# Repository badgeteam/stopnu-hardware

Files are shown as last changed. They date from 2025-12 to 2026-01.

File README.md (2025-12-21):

# STOPNU traffic light controller board

## Introduction

The StopNU board is an interface board design to be used with an Heltec V3 board, with purpose to provide a LoRa synchronized traffic light system.
The board has the ability to process inputs from: an Ambient light sensor, 3 button IO channels, a QWIIC interface.
The board can control LED strips via 5V LED control output lines, and using QWIIC peripherals.
IO is also exposed to the 'Expansion connector', which provides a way to breakout IO to future boards.

## Power

The board will be provided 5V power, stabilized outside of the board.
Because the current consumption is limited to 1A, the board it self cannot provide power to LED's controlled by the board.

Even though 3.3V and 5V pins are provided with the expansion header, the total power of these two power railes combined is limited at 3W.

## Pin-out

### Ambient light sensor

The ambient light sensor this circuit is designed for is the [TEPT4400](https://www.vishay.com/docs/81341/tept4400.pdf), where the sensor is connected between the collector and emitter pin.
The current allowed through the sensor results in a voltage that needs to be decoded by the ESP32 micro controller ADC input pin.

The emitter is is connected to ADC pin GPIO02

### LED control outputs

The LED control output pins are level shifted to 5V TTL, in order to work with the WS2812 addressable LED's or compatible.
The pins are output only as the level shifter only works one way.

| LED output | GPIO |
| --- | --- |
| 1 | GPIO04 |
| 2 | GPIO03 |

### Digital input lines

In order for external input devices to work with the board, 3 input lines have been provided, that are routed through an opto-coupler in order to be more noise resistant.
The IO pins are pulled up to 5V, and need to be pulled down by the input device in order for the board to register an input.

When the pin is pulled down the current through the IO input is 5 mA.

| Button # | GPIO |
| --- | --- |
| 1 | GPIO07 |
| 2 | GPIO06 |
| 3 | GPIO07 |

### QWIIC connector

The QWIIC connector is there to connect external I2C (IIC) sensors and IO modules to the board, providing an extra method of expansion.
The port complies with the pin out and specs as provided by [QWIIC Sparkfun page](https://www.sparkfun.com/qwiic), QWIIC products sold are compatible with this board.

Again for the QWIIC bus 3.3V power supply counts, 3W budget shared with the other peripherals on the board.

| QWIIC pin | GPIO |
| --- | -----  |
| SDA | GPIO34 |
| SCL | GPIO33 |

### Expansion connector

The expansion connector exposes the Heltec V3 pins useable for IO.
The pins that are connected to the buffered outputs on the bottom of the board are also exposed on the header, but without the buffering.

Please be aware that some pins exposed on the header are used by the Heltec V3 internally, and should be used with care.

Here a list of the Heltec V3 board pins and where they connect to on the expansion header.

| pin | GPIO | capable | comments |
| --- | --- | --- | --- |
| 1 | GND | Power | |
| 2 | GND | Power | |
| 3 | GPIO41  | | |
| 4 | GPIO44  | | Heltec V3 UAR_TX |
| 5 | GPIO40  | | Drives Heltec white LED |
| 6 | GPIO43  | | Heltec V3 UART_RX |
| 7 | GPIO39  | | Heltec V3 external power switch |
| 8 | MCU_RST | | Heltec V3 Reset pin |
| 9 | GPIO38  | | Heltec V3 ADC ctrl |
| 10  | GPIO00  | | USER_KEY |
| 11  | GPIO01  | ADC | |
| 12  | GPIO35  | | |
| 13  | GPIO02  | ADC | |
| 14  | GPIO34  | | QWIIC SDA |
| 15  | +3.3V | Power | 3W max (total) |
| 16  | +5V | Power | 3W max (total) |
| 17  | GND | Power | |
| 18  | GND | Power | |
| 19  | GPIO03  | ADC | LED channel 2 |
| 20  | GPIO45  | | |
| 21  | GPIO04  | ADC | LED channel 1 |
| 22  | GPIO33  | | QWIIC SCL |
| 23  | GPIO05  | ADC | Button IN 3 |
| 24  | GPIO46  | | |
| 25  | GPIO06  | ADC/Input only | Button IN 2 |
| 26  | GPIO42  | |
| 27  | GPIO07  | ADC/Input only | Button IN 1 |
| 28  | GPIO26  | | |
| 29  | GND | Power | |
| 30  | GND | Power | |

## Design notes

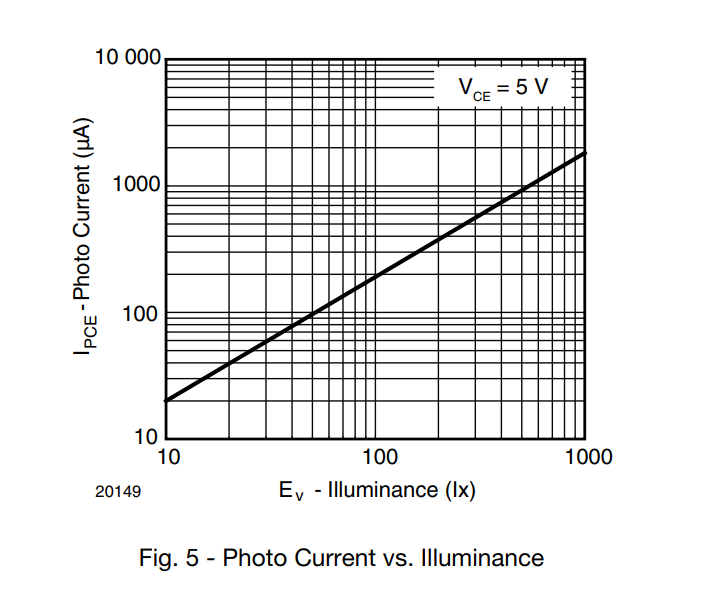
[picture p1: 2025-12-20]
docs/tept4400-i-lum.png

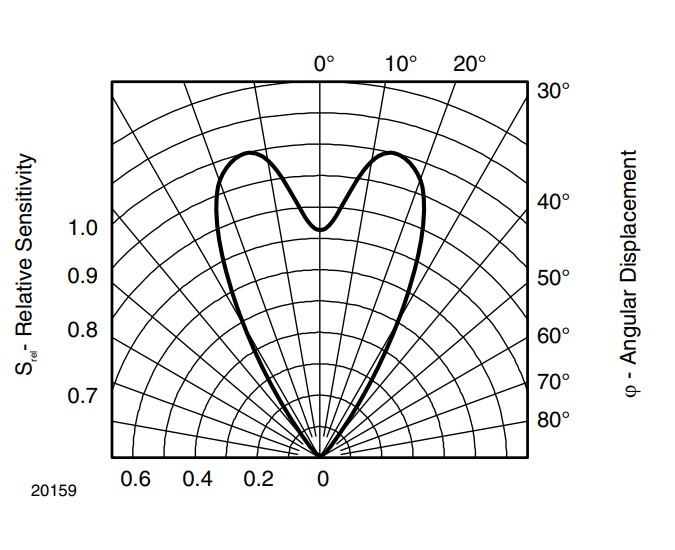
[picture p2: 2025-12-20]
docs/tept4400-directionality.png

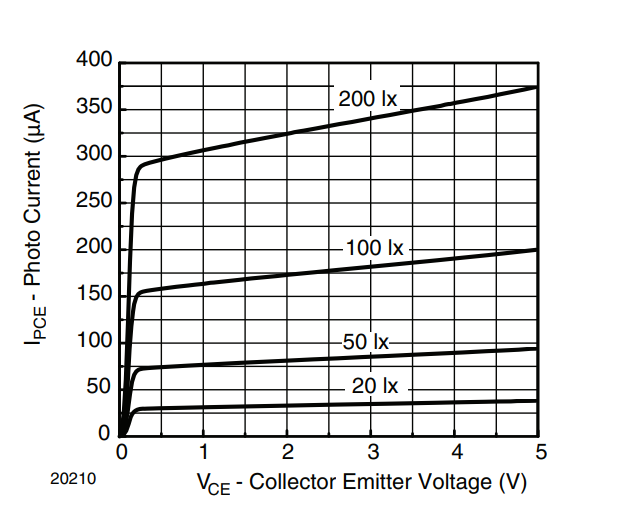
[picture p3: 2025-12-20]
docs/tept4400-i-ce-lux.png

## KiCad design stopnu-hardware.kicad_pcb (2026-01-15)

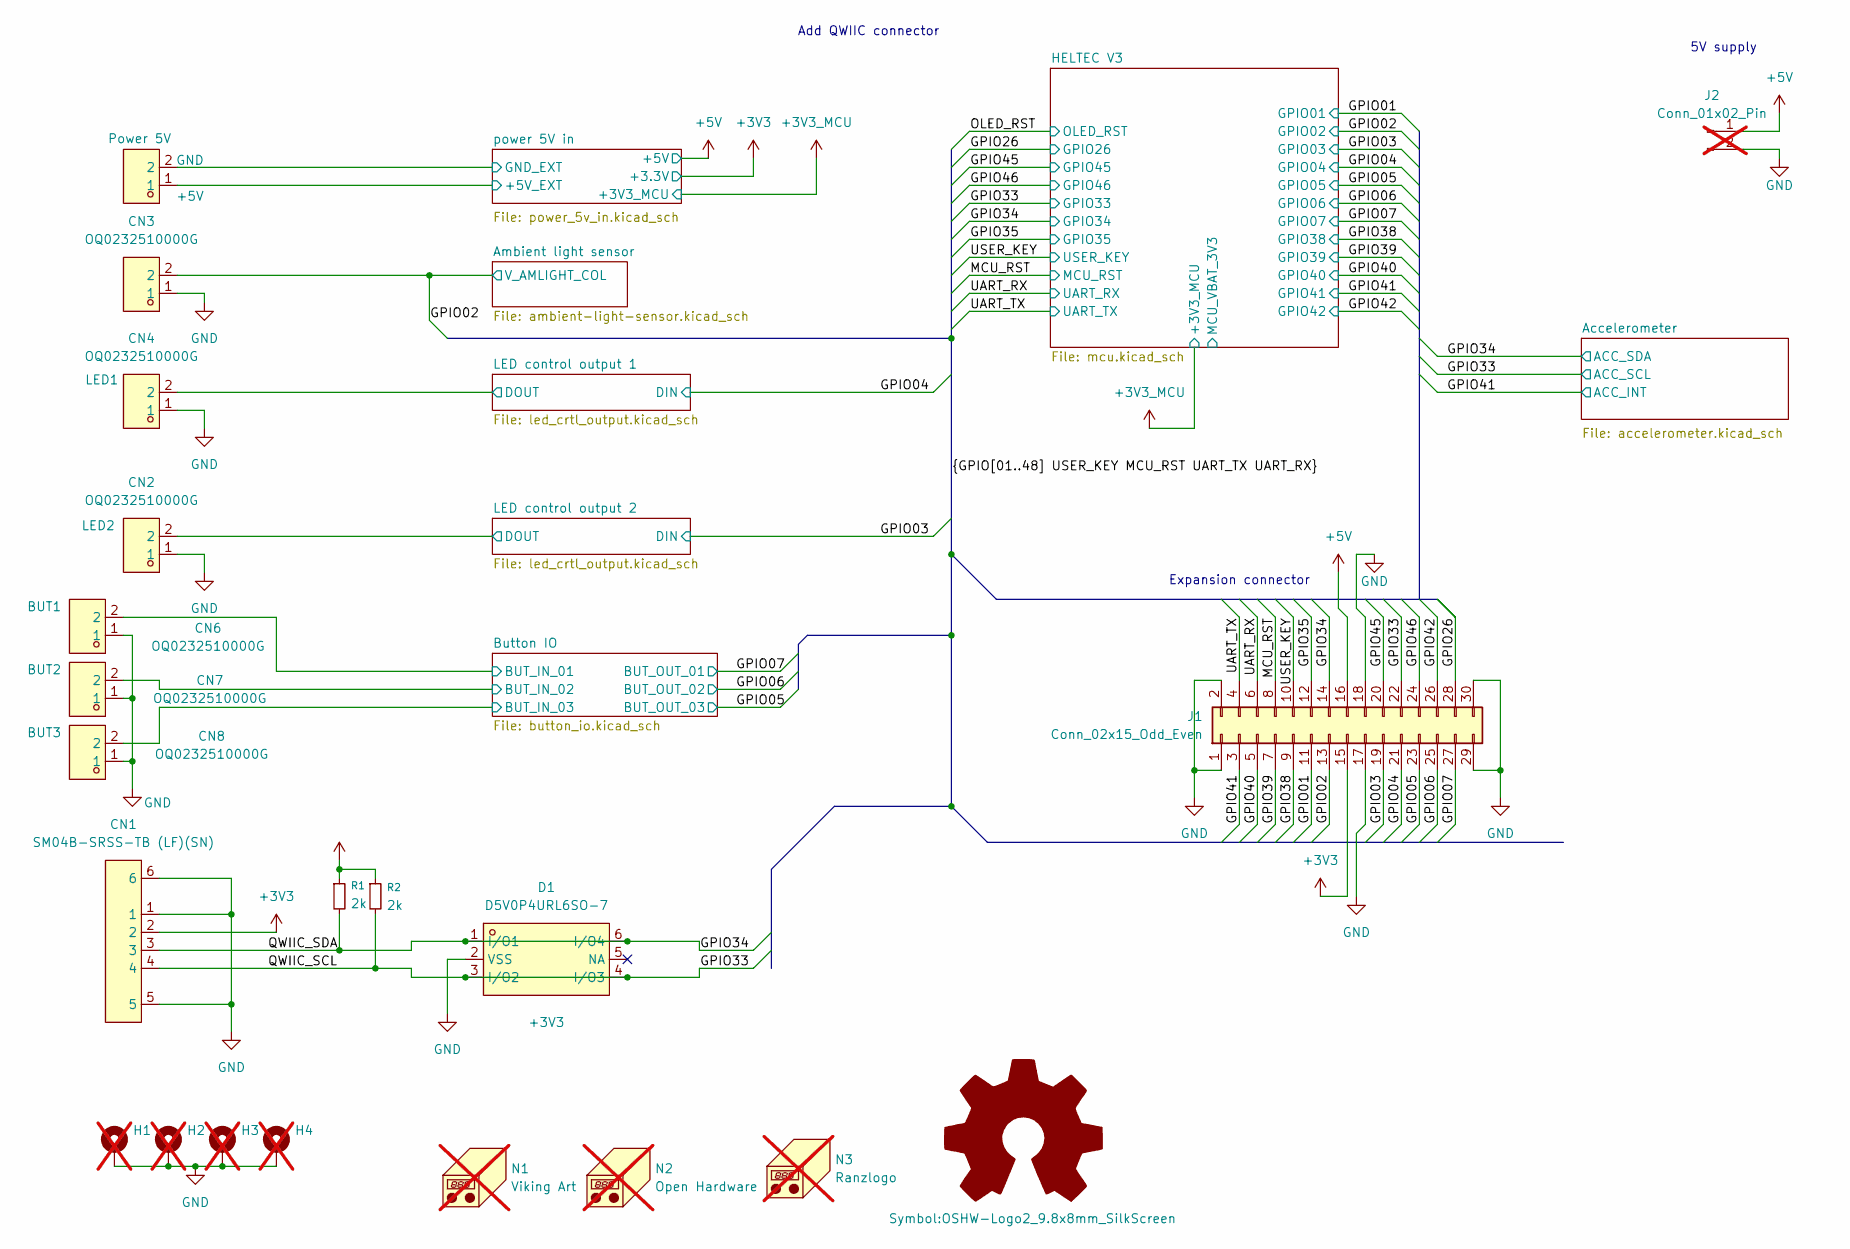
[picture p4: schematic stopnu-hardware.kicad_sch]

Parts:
CN1: SM04B-SRSS-TB (LF)(SN); CONN-SMD_4P-P1.00_SM04B-SRSS-TB-LF-SN; LCSC Part C160404
CN2, CN3, CN4, CN5, CN6, CN7, CN8: OQ0232510000G; CONN-TH_OQ0232510000G; LCSC Part C967073
D1: D5V0P4URL6SO-7; SOT-26_L3.0-W1.6-P0.95-LS2.8-BL; LCSC Part C460591
H1, H2, H3, H4: MountingHole_Pad; MountingHole_4.5mm_Pad_Via; not fitted
J1: Conn_02x15_Odd_Even; PinHeader_2x15_P2.54mm_Horizontal; LCSC C2894995
J2: Conn_01x02_Pin; PinHeader_1x02_P2.54mm_Vertical; LCSC C32713268; not fitted
N1: Viking Art; StopNuVikings; not fitted
N2: Open Hardware; OSHW-Logo2_9.8x8mm_SilkScreen; not fitted
N3: Ranzlogo; goatse_01; not fitted
R1, R2: 2k; R_0603_1608Metric; LCSC C22975

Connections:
+3V3: CN1.2, J1.15, R1.1, R2.1; also elsewhere on the board
+5V: J1.16, J2.1; also elsewhere on the board
/Button IO/BUT_IN_01: CN6.2; also elsewhere on the board
/Button IO/BUT_IN_02: CN7.2; also elsewhere on the board
/Button IO/BUT_IN_03: CN8.2; also elsewhere on the board
/GPIO01: J1.11; also elsewhere on the board
/GPIO02: CN3.2, J1.13; also elsewhere on the board
/GPIO03: J1.19; also elsewhere on the board
/GPIO04: J1.21; also elsewhere on the board
/GPIO05: J1.23; also elsewhere on the board
/GPIO06: J1.25; also elsewhere on the board
/GPIO07: J1.27; also elsewhere on the board
/GPIO26: J1.28; also elsewhere on the board
/GPIO33: CN1.4, D1.3 (I/O2), D1.4 (I/O3), J1.22, R2.2; also elsewhere on the board
/GPIO34: CN1.3, D1.1 (I/O1), D1.6 (I/O4), J1.14, R1.2; also elsewhere on the board
/GPIO35: J1.12; also elsewhere on the board
/GPIO38: J1.9; also elsewhere on the board
/GPIO39: J1.7; also elsewhere on the board
/GPIO40: J1.5; also elsewhere on the board
/GPIO41: J1.3; also elsewhere on the board
/GPIO42: J1.26; also elsewhere on the board
/GPIO45: J1.20; also elsewhere on the board
/GPIO46: J1.24; also elsewhere on the board
/LED control output 1/DOUT: CN4.2; also elsewhere on the board
/LED control output 2/DOUT: CN2.2; also elsewhere on the board
/MCU_RST: J1.8; also elsewhere on the board
/UART_RX: J1.6; also elsewhere on the board
/UART_TX: J1.4; also elsewhere on the board
/USER_KEY: J1.10; also elsewhere on the board
/power 5V in/+5V_EXT: CN5.1; also elsewhere on the board
/power 5V in/GND_EXT: CN5.2; also elsewhere on the board
GND: CN1.1, CN1.5, CN1.6, CN2.1, CN3.1, CN4.1, CN6.1, CN7.1, CN8.1, D1.2 (VSS), H1.1, H2.1, H3.1, H4.1, J1.1, J1.2, J1.17, J1.18, J1.29, J1.30, J2.2; also elsewhere on the board

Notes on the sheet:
5V supply
Add QWIIC connector
Expansion connector

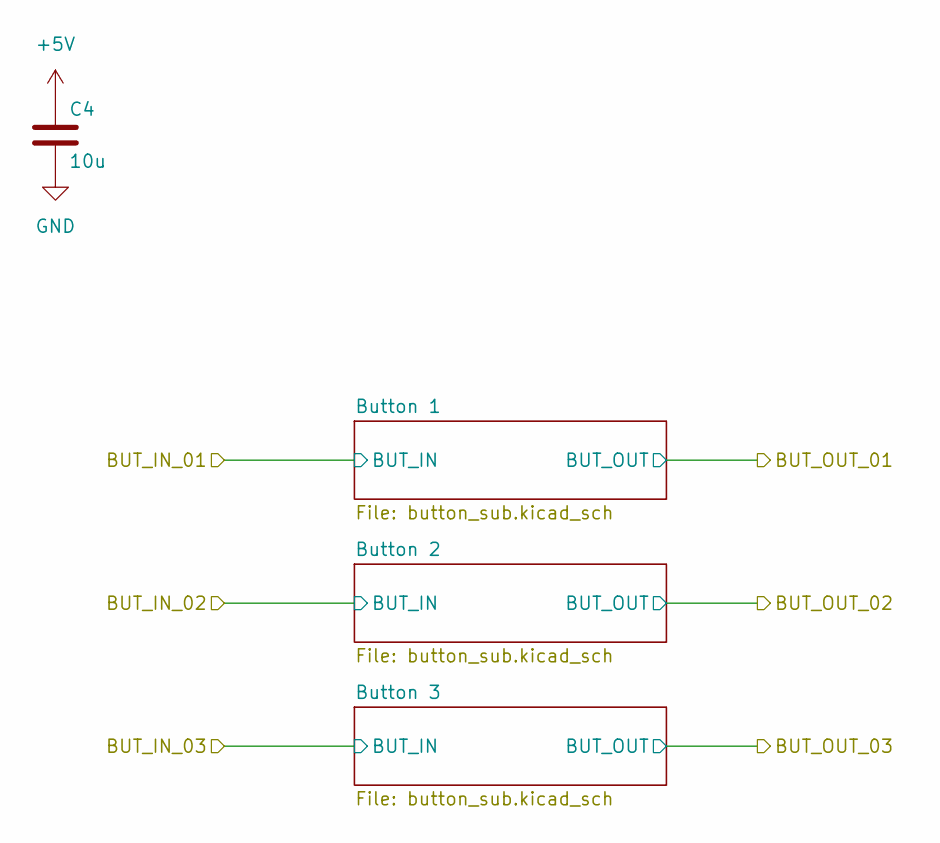
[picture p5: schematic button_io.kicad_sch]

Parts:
C4: 10u; C_0805_2012Metric; LCSC C3039694

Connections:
+5V: C4.1; also elsewhere on the board
GND: C4.2; also elsewhere on the board

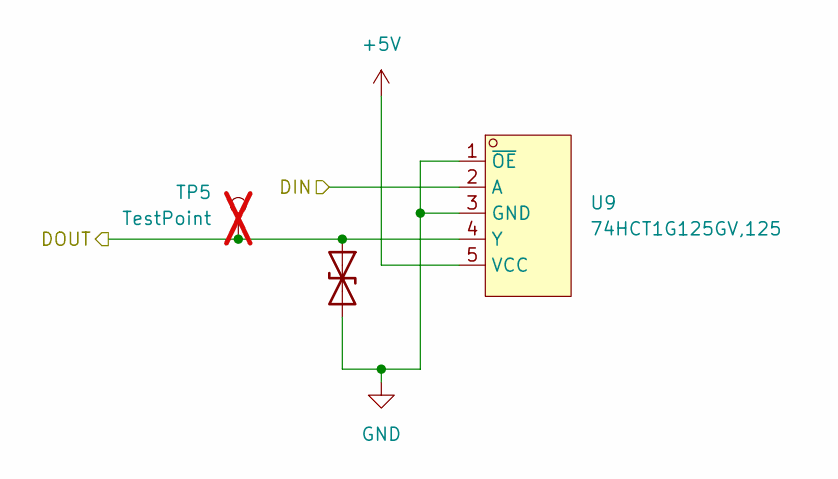
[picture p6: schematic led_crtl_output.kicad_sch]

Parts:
D4: ESD prot.; D_SOD-323; LCSC C22363742
TP5: TestPoint; TestPoint_Pad_D1.0mm; not fitted
U9: 74HCT1G125GV,125; SOT-753_L3.1-W1.7-P0.95-LS3.0-BL; LCSC Part C12502

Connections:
+5V: U9.5 (VCC); also elsewhere on the board
/GPIO04: U9.2 (A); also elsewhere on the board
/LED control output 1/DOUT: D4.1 (A1), TP5.1, U9.4 (Y); also elsewhere on the board
GND: D4.2 (A2), U9.1 (~OE), U9.3 (GND); also elsewhere on the board

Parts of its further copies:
D2: ESD prot.; D_SOD-323; LCSC C22363742
TP3: TestPoint; TestPoint_Pad_D1.0mm; not fitted
U10: 74HCT1G125GV,125; SOT-753_L3.1-W1.7-P0.95-LS3.0-BL; LCSC Part C12502

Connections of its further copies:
+5V: U10.5 (VCC); also elsewhere on the board
/GPIO03: U10.2 (A); also elsewhere on the board
/LED control output 2/DOUT: D2.1 (A1), TP3.1, U10.4 (Y); also elsewhere on the board
GND: D2.2 (A2), U10.1 (~OE), U10.3 (GND); also elsewhere on the board

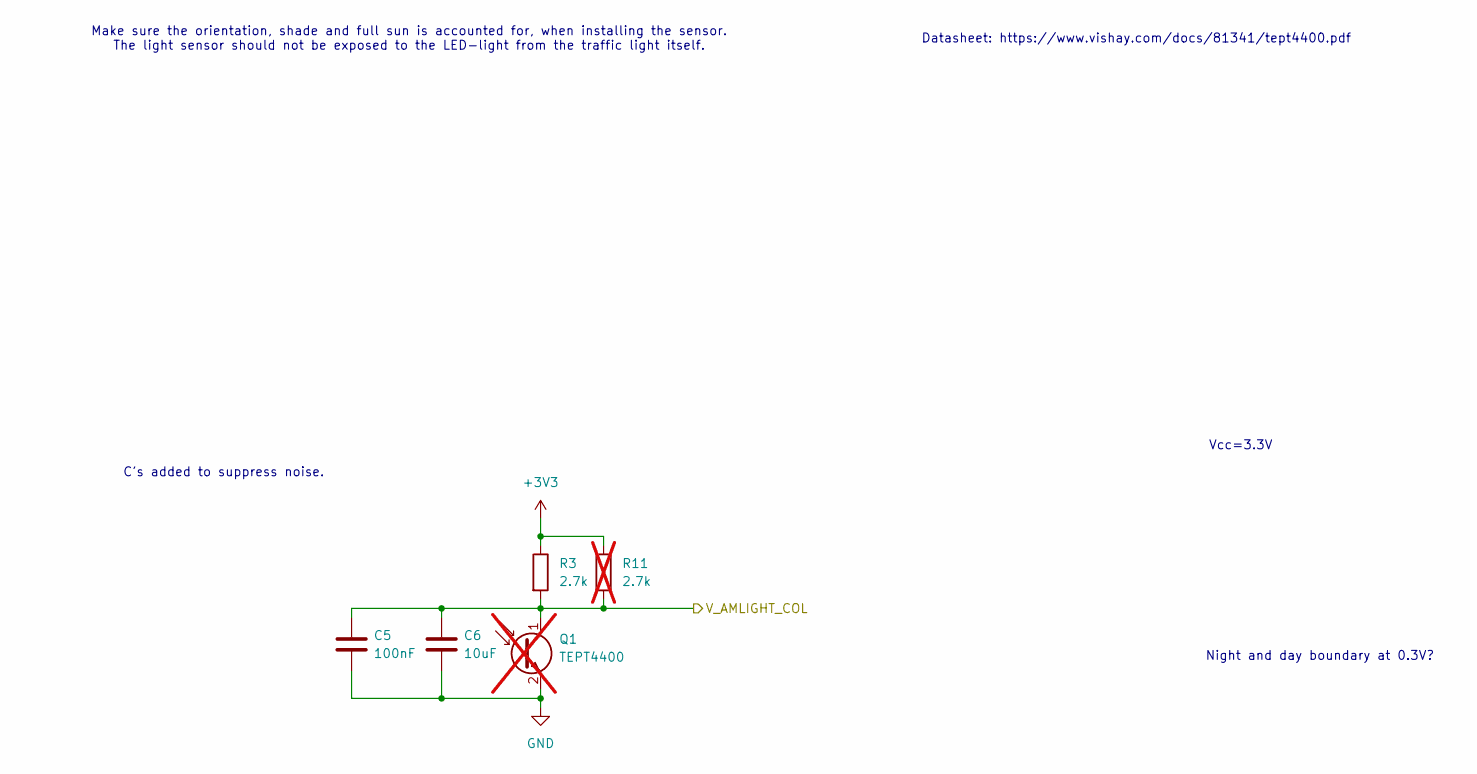
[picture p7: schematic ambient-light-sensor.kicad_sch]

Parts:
C5: 100nF; C_0805_2012Metric; LCSC C49678
C6: 10uF; C_0805_2012Metric; LCSC C440198
Q1: TEPT4400; PinHeader_1x02_P1.00mm_Horizontal; not fitted
R3: 2.7k; R_0603_1608Metric; LCSC C13167
R11: 2.7k; R_0603_1608Metric; LCSC C13167; not fitted

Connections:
+3V3: R3.1, R11.1; also elsewhere on the board
/GPIO02: C5.1, C6.1, Q1.1 (C), R3.2, R11.2; also elsewhere on the board
GND: C5.2, C6.2, Q1.2 (E); also elsewhere on the board

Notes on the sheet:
Night and day boundary at 0.3V?
Make sure the orientation, shade and full sun is accounted for, when installing the sensor. The light sensor should not be exposed to the LED-light from the traffic light itself.
Vcc=3.3V
C's added to suppress noise.
Datasheet: https://www.vishay.com/docs/81341/tept4400.pdf

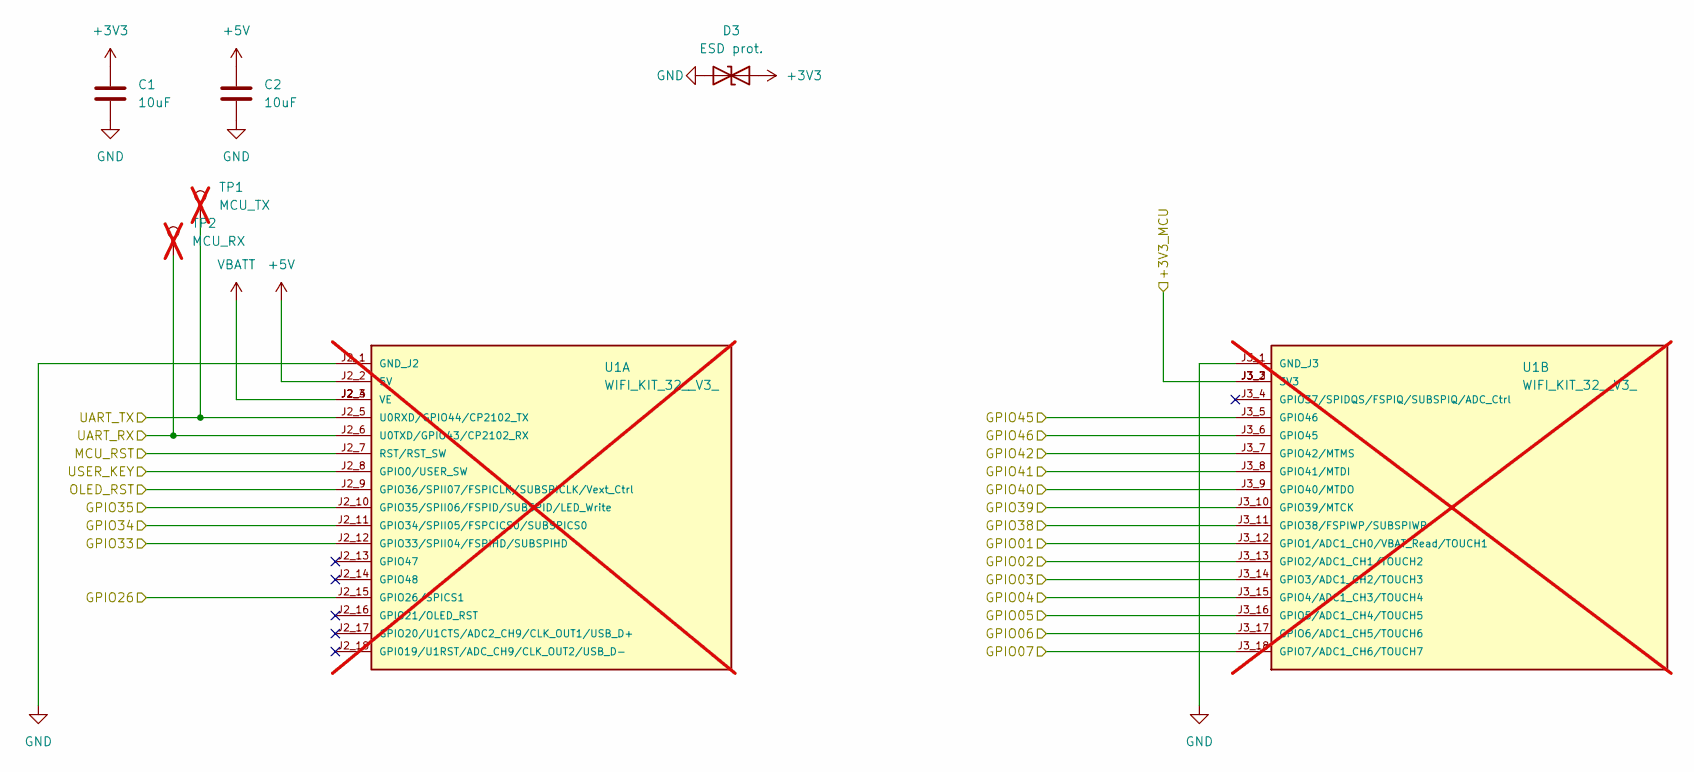
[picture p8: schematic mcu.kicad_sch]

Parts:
C1, C2: 10uF; C_0805_2012Metric; LCSC C440198
D3: ESD prot.; D_SOD-323; LCSC C22363742
TP1: MCU_TX; TestPoint_Pad_D1.0mm; not fitted
TP2: MCU_RX; TestPoint_Pad_D1.0mm; not fitted
U1: WIFI_KIT_32__V3_; MODULE_WIFI_KIT_32__V3_; PARTREV Rev 1.1; not fitted

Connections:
+3V3: C1.1, D3.1 (A1); also elsewhere on the board
+3V3_MCU: U1.J3_2 (3V3), U1.J3_3 (3V3); also elsewhere on the board
+5V: C2.1, U1.J2_2 (5V); also elsewhere on the board
/GPIO01: U1.J3_12 (GPIO1/ADC1_CH0/VBAT_Read/TOUCH1); also elsewhere on the board
/GPIO02: U1.J3_13 (GPIO2/ADC1_CH1/TOUCH2); also elsewhere on the board
/GPIO03: U1.J3_14 (GPIO3/ADC1_CH2/TOUCH3); also elsewhere on the board
/GPIO04: U1.J3_15 (GPIO4/ADC1_CH3/TOUCH4); also elsewhere on the board
/GPIO05: U1.J3_16 (GPIO5/ADC1_CH4/TOUCH5); also elsewhere on the board
/GPIO06: U1.J3_17 (GPIO6/ADC1_CH5/TOUCH6); also elsewhere on the board
/GPIO07: U1.J3_18 (GPIO7/ADC1_CH6/TOUCH7); also elsewhere on the board
/GPIO26: U1.J2_15 (GPIO26/SPICS1); also elsewhere on the board
/GPIO33: U1.J2_12 (GPIO33/SPII04/FSPIHD/SUBSPIHD); also elsewhere on the board
/GPIO34: U1.J2_11 (GPIO34/SPII05/FSPCICS0/SUBSPICS0); also elsewhere on the board
/GPIO35: U1.J2_10 (GPIO35/SPII06/FSPID/SUBSPID/LED_Write); also elsewhere on the board
/GPIO38: U1.J3_11 (GPIO38/FSPIWP/SUBSPIWP); also elsewhere on the board
/GPIO39: U1.J3_10 (GPIO39/MTCK); also elsewhere on the board
/GPIO40: U1.J3_9 (GPIO40/MTDO); also elsewhere on the board
/GPIO41: U1.J3_8 (GPIO41/MTDI); also elsewhere on the board
/GPIO42: U1.J3_7 (GPIO42/MTMS); also elsewhere on the board
/GPIO45: U1.J3_5 (GPIO46); also elsewhere on the board
/GPIO46: U1.J3_6 (GPIO45); also elsewhere on the board
/MCU_RST: U1.J2_7 (RST/RST_SW); also elsewhere on the board
/OLED_RST: U1.J2_9 (GPIO36/SPII07/FSPICLK/SUBSPICLK/Vext_Ct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)
/UART_RX: TP2.1, U1.J2_6 (U0TXD/GPIO43/CP2102_RX); also elsewhere on the board
/UART_TX: TP1.1, U1.J2_5 (U0RXD/GPIO44/CP2102_TX); also elsewhere on the board
/USER_KEY: U1.J2_8 (GPIO0/USER_SW); also elsewhere on the board
GND: C1.2, C2.2, D3.2 (A2), U1.J2_1 (GND_J2), U1.J3_1 (GND_J3); also elsewhere on the board
VBATT: U1.J2_3 (VE), U1.J2_4 (VE)

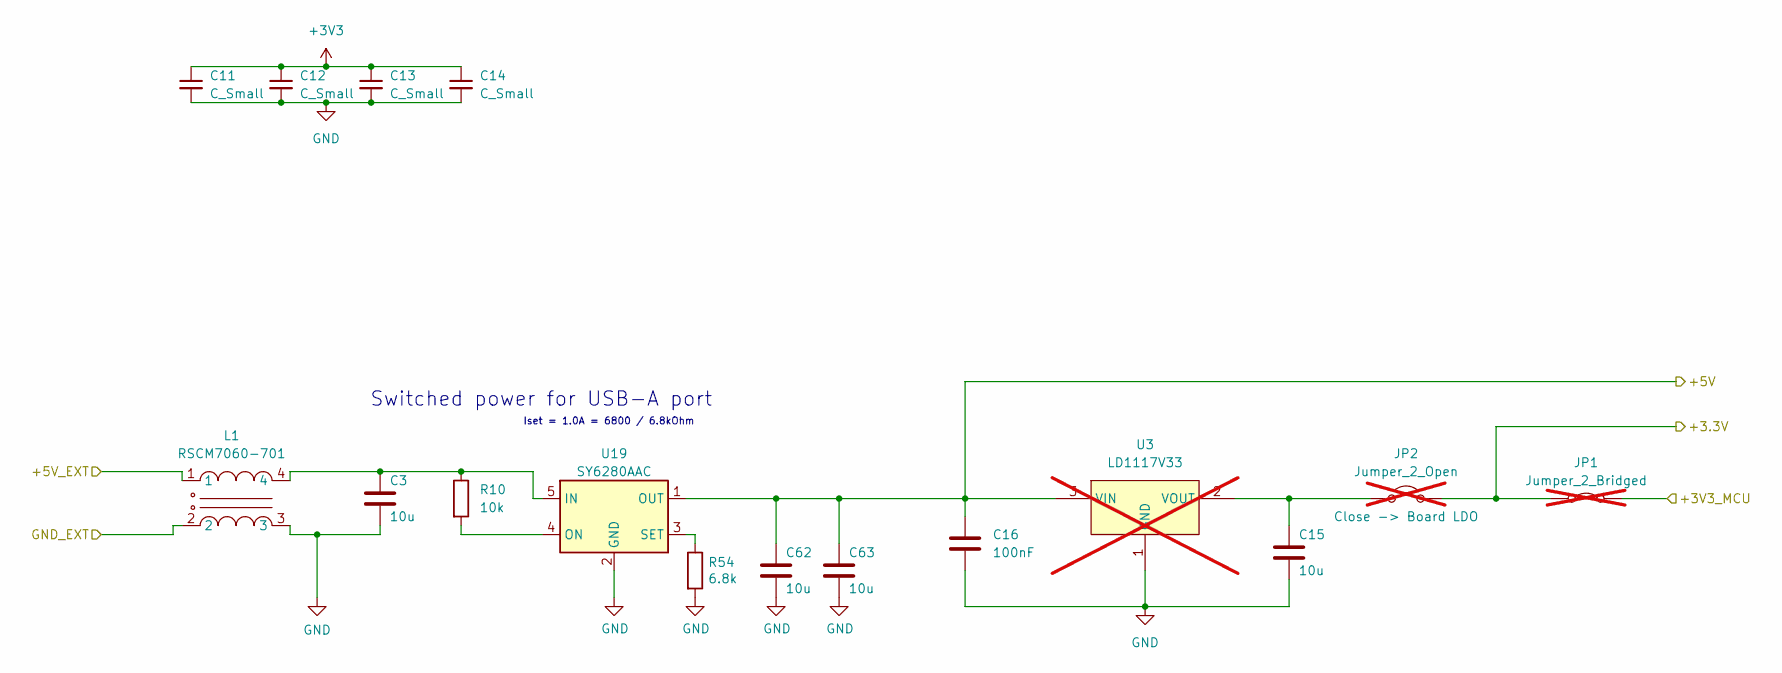
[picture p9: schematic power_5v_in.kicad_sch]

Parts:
C3, C15, C62, C63: 10u; C_0805_2012Metric; LCSC C3039694
C11, C12, C13, C14: C_Small; C_0603_1608Metric; LCSC C57112
C16: 100nF; C_0805_2012Metric; LCSC C49678
JP1: Jumper_2_Bridged; SolderJumper-2_P1.3mm_Bridged_RoundedPad1.0x1.5mm; not fitted
JP2: Jumper_2_Open; SolderJumper-2_P1.3mm_Open_RoundedPad1.0x1.5mm; not fitted
L1: RSCM7060-701; FILTER-SMD_4P-L7.0-W6.0-P3.00-TL; LCSC Part C32712963
R10: 10k; R_0603_1608Metric; LCSC C25804
R54: 6.8k; R_0402_1005Metric; LCSC C25917
U3: LD1117V33; TO-220-3_L10.0-W4.5-P2.54-L; LCSC Part C283467; not fitted
U19: SY6280AAC; SOT-23-5; LCSC C55136

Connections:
+3V3: C11.1, C12.1, C13.1, C14.1, JP1.1 (A), JP2.2 (B); also elsewhere on the board
+3V3_MCU: JP1.2 (B); also elsewhere on the board
+5V: C16.1, C62.1, C63.1, U3.3 (VIN), U19.1 (OUT); also elsewhere on the board
/power 5V in/+5V_EXT: L1.1; also elsewhere on the board
/power 5V in/GND_EXT: L1.2; also elsewhere on the board
GND: C3.2, C11.2, C12.2, C13.2, C14.2, C15.2, C16.2, C62.2, C63.2, L1.3, R54.2, U3.1 (GND), U19.2 (GND); also elsewhere on the board
unnamed: C15.1, JP2.1 (A), U3.2 (VOUT)
unnamed: C3.1, L1.4, R10.1, U19.5 (IN)
unnamed: R10.2, U19.4 (ON)
unnamed: R54.1, U19.3 (SET)

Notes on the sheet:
Switched power for USB-A port
Iset = 1.0A = 6800 / 6.8kOhm

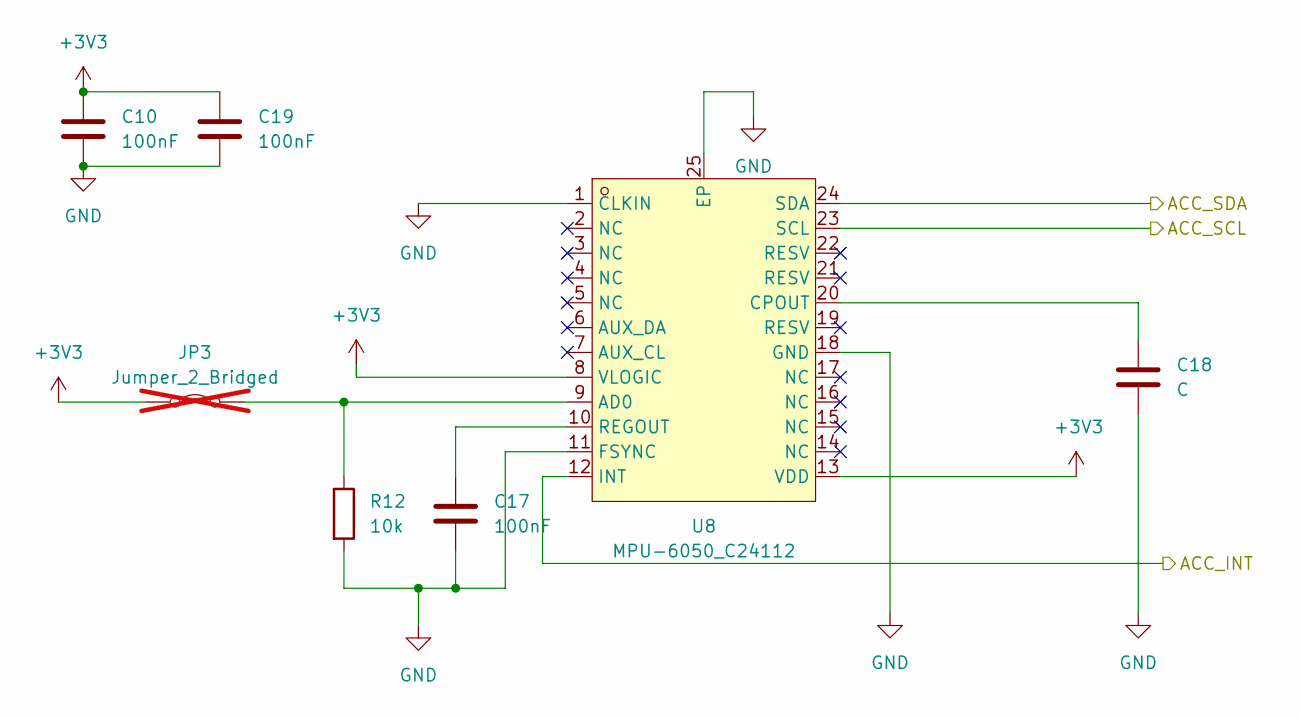
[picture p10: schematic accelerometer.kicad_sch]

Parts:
C10, C17, C19: 100nF; C_0805_2012Metric; LCSC C49678
C18: C; C_0603_1608Metric; LCSC C178417
JP3: Jumper_2_Bridged; SolderJumper-2_P1.3mm_Bridged_RoundedPad1.0x1.5mm; not fitted
R12: 10k; R_0603_1608Metric; LCSC C25804
U8: MPU-6050_C24112; QFN-24_L4.0-W4.0-P0.50-BL-EP2.7; LCSC Part C24112

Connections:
+3V3: C10.1, C19.1, JP3.1 (A), U8.8 (VLOGIC), U8.13 (VDD); also elsewhere on the board
/GPIO33: U8.23 (SCL); also elsewhere on the board
/GPIO34: U8.24 (SDA); also elsewhere on the board
/GPIO41: U8.12 (INT); also elsewhere on the board
GND: C10.2, C17.2, C18.2, C19.2, R12.2, U8.1 (CLKIN), U8.11 (FSYNC), U8.18 (GND), U8.25 (EP); also elsewhere on the board
unnamed: JP3.2 (B), R12.1, U8.9 (AD0)
unnamed: C18.1, U8.20 (CPOUT)
unnamed: C17.1, U8.10 (REGOUT)

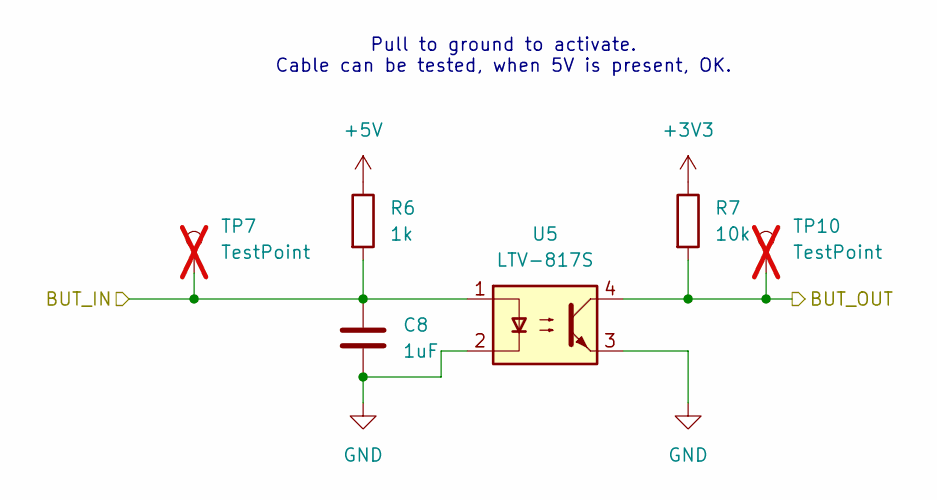
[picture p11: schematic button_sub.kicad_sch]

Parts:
C8: 1uF; C_0603_1608Metric; LCSC C15849
R6: 1k; R_0603_1608Metric; LCSC C21190
R7: 10k; R_0603_1608Metric; LCSC C25804
TP7, TP10: TestPoint; TestPoint_Pad_D1.0mm; not fitted
U5: LTV-817S; SMDIP-4_W9.53mm; LCSC C109227

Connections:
+3V3: R7.1; also elsewhere on the board
+5V: R6.1; also elsewhere on the board
/Button IO/BUT_IN_02: C8.1, R6.2, TP7.1, U5.1; also elsewhere on the board
/GPIO06: R7.2, TP10.1, U5.4; also elsewhere on the board
GND: C8.2, U5.2, U5.3; also elsewhere on the board

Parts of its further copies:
C7, C9: 1uF; C_0603_1608Metric; LCSC C15849
R4, R8: 1k; R_0603_1608Metric; LCSC C21190
R5, R9: 10k; R_0603_1608Metric; LCSC C25804
TP8, TP9, TP11, TP12: TestPoint; TestPoint_Pad_D1.0mm; not fitted
U6, U7: LTV-817S; SMDIP-4_W9.53mm; LCSC C109227

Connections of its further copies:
+3V3: R5.1, R9.1; also elsewhere on the board
+5V: R4.1, R8.1; also elsewhere on the board
/Button IO/BUT_IN_01: C7.1, R4.2, TP9.1, U7.1; also elsewhere on the board
/Button IO/BUT_IN_03: C9.1, R8.2, TP8.1, U6.1; also elsewhere on the board
/GPIO05: R9.2, TP11.1, U6.4; also elsewhere on the board
/GPIO07: R5.2, TP12.1, U7.4; also elsewhere on the board
GND: C7.2, C9.2, U6.2, U6.3, U7.2, U7.3; also elsewhere on the board

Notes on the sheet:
Pull to ground to activate. Cable can be tested, when 5V is present, OK.

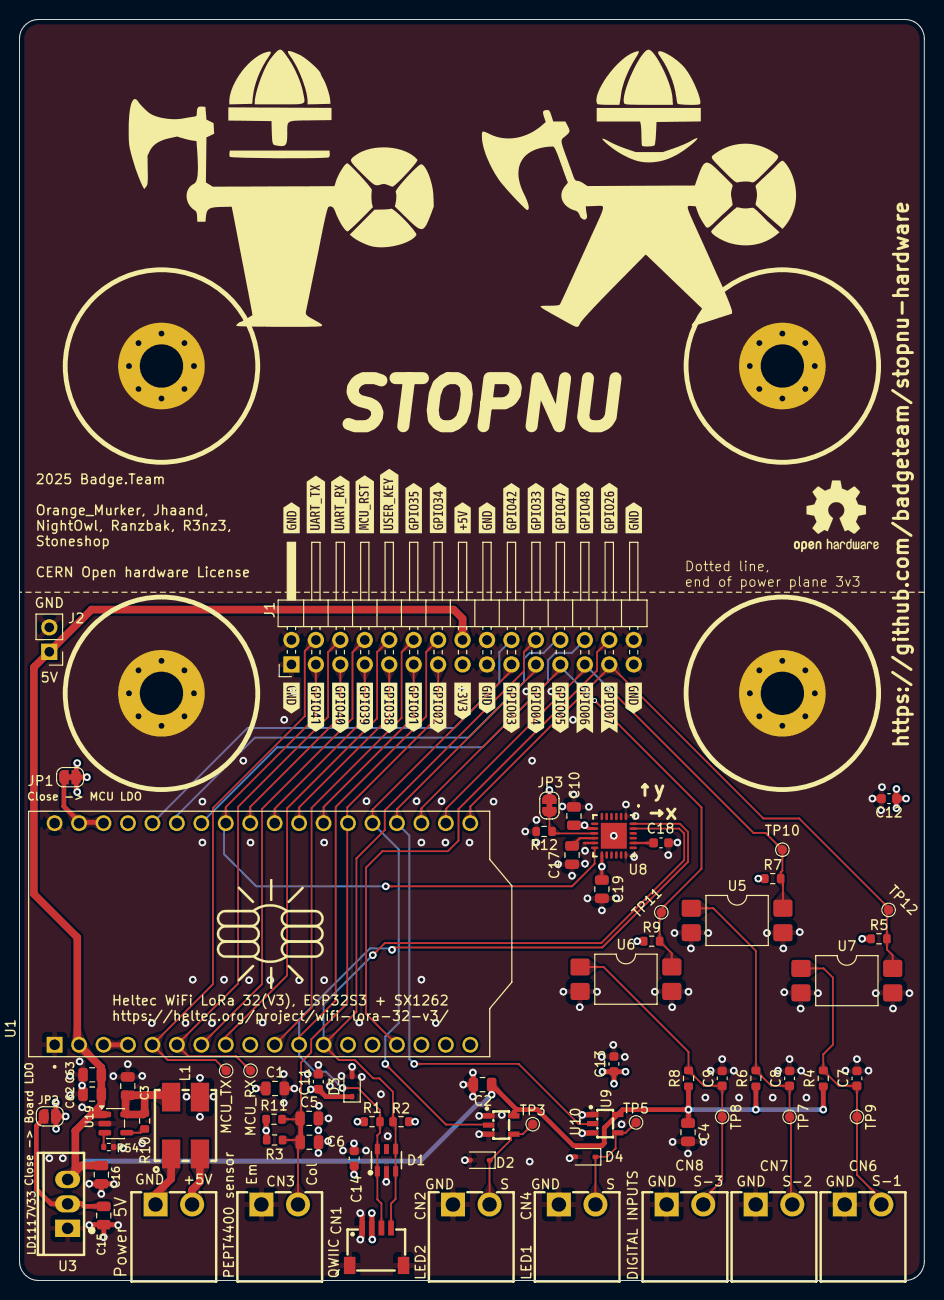
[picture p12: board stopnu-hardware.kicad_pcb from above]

Board: 4 copper layers, 94.0 x 131.0 mm, 108 parts (0 on the bottom side), 41 nets.

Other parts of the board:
kibuzzard-6946CCA1, kibuzzard-6946CCA1#2, kibuzzard-6946CCA1#3, kibuzzard-6946CCA1#4, kibuzzard-6946CCA1#5, kibuzzard-6946CCA1#6: G***; kibuzzard-6946CCA1
kibuzzard-6946CDDB: G***; kibuzzard-6946CDDB
kibuzzard-6946CE2E: G***; kibuzzard-6946CE2E
kibuzzard-6946CE3C: G***; kibuzzard-6946CE3C
kibuzzard-6946CE4B: G***; kibuzzard-6946CE4B
kibuzzard-6946CE20: G***; kibuzzard-6946CE20
kibuzzard-6946CE89: G***; kibuzzard-6946CE89
kibuzzard-6946CE92: G***; kibuzzard-6946CE92
kibuzzard-6946CE98: G***; kibuzzard-6946CE98
kibuzzard-6946CEA1: G***; kibuzzard-6946CEA1
kibuzzard-6946CEAD: G***; kibuzzard-6946CEAD
kibuzzard-6946CEFA: G***; kibuzzard-6946CEFA
kibuzzard-6946CF2B: G***; kibuzzard-6946CF2B
kibuzzard-6946CF08: G***; kibuzzard-6946CF08
kibuzzard-6946CF12: G***; kibuzzard-6946CF12
kibuzzard-6946CF20: G***; kibuzzard-6946CF20
kibuzzard-6946CF52: G***; kibuzzard-6946CF52
kibuzzard-6946CF89: G***; kibuzzard-6946CF89
kibuzzard-6946CF95: G***; kibuzzard-6946CF95
kibuzzard-6946CFA1: G***; kibuzzard-6946CFA1
kibuzzard-6946CFA8: G***; kibuzzard-6946CFA8
kibuzzard-69470A2F: G***; kibuzzard-69470A2F
kibuzzard-69470A3B: G***; kibuzzard-69470A3B
kibuzzard-69470A66: G***; kibuzzard-69470A66
kibuzzard-69470A71: G***; kibuzzard-69470A71

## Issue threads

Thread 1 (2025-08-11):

Power source

renzenicolai, 2025-08-11:

ranzbak, 2025-08-30:
I guess we can decouple this be not adding DC-DC converter to the PCB.
We can have a battery voltage metric, which has a range 0V-100V.
Since the DC-DC converter puts out 5V we can feed the PCB of that.

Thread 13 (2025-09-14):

Connectors expected on the PCB

ranzbak, 2025-09-14:
The PCB needs to connect to the rest of the setup in different ways.

The USB-C port that already comes with the Heltec-V3 is one.

But, There are :

3 wire - IO connections, needed to connect the buttons or other stuff to.
3 wire - High current (5V) connection, (0V, Current in, Current out)
2 wire - Low current, low voltage to the ambient light sensor.
2 wire - Battery voltage 100V max (0V, VBAT) to connect up to a voltage divider

In practice, the high current, high voltage are important, the pin count is not that important.
Can you provide me with the generic type of connectors you expect?

ranzbak, 2025-09-14:
Suggestion:

Connector: https://www.lcsc.com/product-detail/C3580229.html
Housing: https://www.lcsc.com/product-detail/C7016721.html

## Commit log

2025-09-14 First commit very incomplete setup.
    [50v_batt_to_adc.kicad_sch, ambient-light-sensor.kicad_sch, button_io.kicad_sch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]
2025-09-15 Place opto couplers and some connectors.
    [50v_batt_to_adc.kicad_sch, ambient-light-sensor.kicad_sch, button_sub.kicad_sch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]
2025-09-15 changed driver IC for LED signal to 74HCT1G125GW
    [led_crtl_output.kicad_sch, stopnu-hardware.kicad_pcb]
2025-09-20 Added input, board square, power, optional LDO.
    [power_5v_in.kicad_sch]
2025-09-20 Push schematic stuff missed before.
    [50v_batt_to_adc.kicad_sch, mcu.kicad_sch, stopnu-hardware.kicad_pcb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]
2025-12-16 Some extra work for building the rats nest.
    [mcu.kicad_sch, stopnu-hardware.kicad_pcb, stopnu-hardware.kicad_sch]
2025-12-17 WIP: Routed version, for first feedback round
    [led_crtl_output.kicad_sch, mcu.kicad_sch, power_5v_in.kicad_sch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]
2025-12-17 WIP: Added StopNu temp text label.
    [stopnu-hardware.kicad_pcb]
2025-12-18 Add some vias around GND, STOPNU label
    [stopnu-hardware.kicad_pcb]
2025-12-18 moved heltec V3 4mm down
    [stopnu-hardware.kicad_pcb]
2025-12-18 Rotate Optos 90' to handle pcb bending better.
    [stopnu-hardware.kicad_pcb]
2025-12-18 minor improvements.
    [stopnu-hardware.kicad_pcb, stopnu-hardware.kicad_sch]
2025-12-18 Names of people that contributed.
    [stopnu-hardware.kicad_pcb]
2025-12-18 Mounting holes to 4.5mm.
    [stopnu-hardware.kicad_pcb, stopnu-hardware.kicad_sch]
2025-12-19 Fixed USB-pin routing, some other cleanups.
    [stopnu-hardware.kicad_pcb, stopnu-hardware.kicad_sch]
2025-12-20 Labeled expansion port, fixed en pin U19 (high)
    [ambient-light-sensor.kicad_sch, button_io.kicad_sch, button_sub.kicad_sch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]
2025-12-20 Fixed some pinout issues.
    [mcu.kicad_sch, stopnu-hardware.kicad_pcb, stopnu-hardware.kicad_sch]
2025-12-21 Add README.md, make power input more intuitive in schematic.
    [button_sub.kicad_sch, mcu.kicad_sch, power_5v_in.kicad_sch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]
2025-12-21 Push, forgot to save.
    [stopnu-hardware.kicad_pcb]
2025-12-21 Fixed issues + added 3 2 pin connectors for digital (button) inputs.
    [power_5v_in.kicad_sch, stopnu-hardware.kicad_pcb, stopnu-hardware.kicad_sch]
2025-12-21 Fixed labels 3 digital input channels.
    [stopnu-hardware.kicad_pcb, stopnu-hardware.kicad_sch]
2025-12-21 Changed ambient light sensor to pull-up design.
    [ambient-light-sensor.kicad_sch, stopnu-hardware.kicad_pcb, stopnu-hardware.kicad_sch]
2025-12-21 Fix D1 3D model, to be placed correctly.
    [stopnu-hardware.kicad_pcb]
2025-12-21 Changed capacitors to span the TEPT4400
    [ambient-light-sensor.kicad_sch, stopnu-hardware.kicad_pcb]
2025-12-21 Power plane not under top of PCB, add 5V to plug in stuff just in case.
    [power_5v_in.kicad_sch, stopnu-hardware.kicad_pcb, stopnu-hardware.kicad_sch]
2025-12-21 Initial MPU6050 addition.
    [accelerometer.kicad_sch, stopnu-hardware.kicad_pcb, stopnu-hardware.kicad_sch]
2025-12-21 Applied rules checker.
    [stopnu-hardware.kicad_pcb]
2025-12-23 Update viking footprint art.
    [stopnu-hardware.kicad_pcb]
2026-01-08 Straightened a track between D2 and CN2
    [stopnu-hardware.kicad_pcb]
2026-01-11 Fixed fabrication files, so PCBA will work with the correct rotation of the components.
    [accelerometer.kicad_sch, ambient-light-sensor.kicad_sch, button_io.kicad_sch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]
2026-01-12 Add orientation mark for accelerometer.
    [stopnu-hardware.kicad_pcb]
2026-01-15 Fixed issue with too little of a component for second prod run.
    [led_crtl_output.kicad_sch, stopnu-hardware.kicad_pcb]

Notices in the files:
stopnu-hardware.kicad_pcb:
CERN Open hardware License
